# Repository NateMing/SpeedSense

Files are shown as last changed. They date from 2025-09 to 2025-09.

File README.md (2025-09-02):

# Radar Speed Sign - Custom PCBs

Custom PCB designs for SpeedSense, developed using KiCAD.

## Project Overview

This repository contains the custom PCB designs created for SpeedSense. The PCBs include a main control board and a custom 7-segment display module designed specifically for this application.

## Project Structure

```
├── SDP25_MainPCB_V2/          # Latest main PCB design (v2.1)
├── SDP25_MainPCB/             # Original main PCB design
├── Drill Files/               # Manufacturing files
│   ├── Main PCB 2.1/         # Latest drill files
│   ├── Main PCB/             # Original drill files
│   └── 7 seg/                # 7-segment display drill files
└── segment.kicad_pcb          # 7-segment display PCB
```

## Hardware Components

### Main Control PCB (v2.1)
- **File**: `SDP25_MainPCB_V2.kicad_pcb`
- **Purpose**: Main control board for radar speed sign system
- **Features**: 4-layer PCB design with power and ground planes
- **Layers**: Front/Back copper, Power, Ground
- **Design Rules**: 0.2mm minimum clearance, 0.25mm minimum track width

### Custom 7-Segment Display PCB
- **File**: `segment.kicad_pcb`
- **Purpose**: Large format 7-segment display module for vehicle speed display

## Getting Started

### Prerequisites
- KiCAD 7.0 or later

## Manufacturing Files

Ready-to-manufacture Gerber files are available in:
- `SDP25_MainPCB_V2/Gerbers/` - Latest main PCB
- `Drill Files/Main PCB 2.1/` - Corresponding drill files
- `Drill Files/7 seg/` - 7-segment display files

### File Types Included
- **Gerber files** (.gtl, .gbl, .gts, .gbs, etc.)
- **Drill files** (.drl)
- **Pick and place** (.gbr)
- **Job files** (.gbrjob)

## Design Specifications

- **Board thickness**: Standard 1.6mm
- **Minimum track width**: 0.25mm
- **Minimum via size**: 0.5mm diameter
- **Minimum hole size**: 0.3mm
- **Layer count**: 4 layers (Main PCB v2.1)

## Version History

- **v2.1** (Latest) - 4-layer design with improved power distribution
- **v1.0** - Initial 2-layer design

## Project Context

These PCBs are part of a larger radar speed sign system developed as a Senior Design Project (SDP). The complete system includes:
- Radar sensor integration
- Microcontroller-based speed processing
- Custom display driver circuitry
- Power management systems

This repository contains only the custom PCB designs created specifically for this project.

## License

This project is for educational purposes as part of academic coursework.

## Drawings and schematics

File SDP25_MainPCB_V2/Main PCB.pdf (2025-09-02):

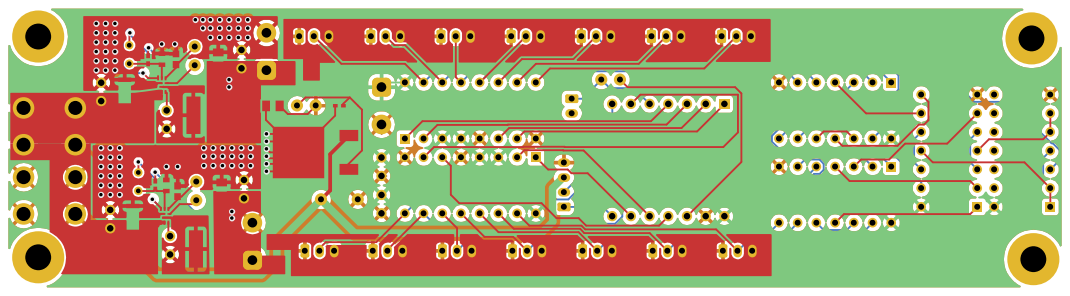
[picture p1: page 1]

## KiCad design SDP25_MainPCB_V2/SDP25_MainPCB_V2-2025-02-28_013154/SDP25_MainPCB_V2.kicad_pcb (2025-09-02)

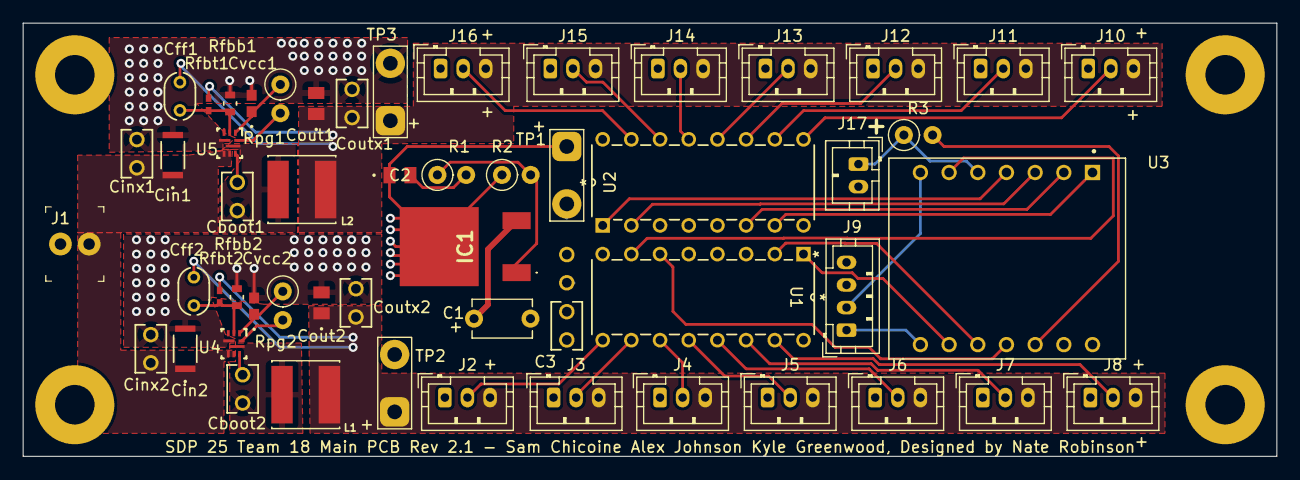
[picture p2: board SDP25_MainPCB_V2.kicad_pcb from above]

Board: 4 copper layers, 111.0 x 38.4 mm, 55 parts (1 on the bottom side), 42 nets.

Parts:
C1: 10uF; C_Disc_D5.1mm_W3.2mm_P5.00mm
C2: 22uF; CAP_GRM21B_MUR
C3, C4: 0.1uF; CAP_FG18_TDK
Cboot1, Cboot2: 0.1uF; CAP_FG18_TDK
Cff1, Cff2: 15pF; CAP_FA18_TDK
Cin1, Cin2: 33uF; CAP_3216_TDK
Cinx1, Cinx2: 0.1uF; CAP_FG18_TDK
Cout1, Cout2: 22uF; CAP_GRM21B_MUR
Coutx1, Coutx2: 0.1uF; CAP_FG18_TDK
Cvcc1, Cvcc2: 1uF; cap_UMK107ABJ474KA-T_TAY
IC1: 5V Voltage Reg.; AZ1084CDADJTRG1
J1: Battery Conn; PinHeader_1x2_P2.54mm_Drill1.02mm
J2: D1PCB1; JST_PH_B3B-PH-K_1x03_P2.00mm_Vertical
J3: D1PCB2; JST_PH_B3B-PH-K_1x03_P2.00mm_Vertical
J4: D1PCB3; JST_PH_B3B-PH-K_1x03_P2.00mm_Vertical
J5: D1PCB4; JST_PH_B3B-PH-K_1x03_P2.00mm_Vertical
J6: D1PCB5; JST_PH_B3B-PH-K_1x03_P2.00mm_Vertical
J7: D1PCB6; JST_PH_B3B-PH-K_1x03_P2.00mm_Vertical
J8: D1PCB7; JST_PH_B3B-PH-K_1x03_P2.00mm_Vertical
J9: Radar Conn; JST_PH_B4B-PH-K_1x04_P2.00mm_Vertical
J10: D2PCB1; JST_PH_B3B-PH-K_1x03_P2.00mm_Vertical
J11: D2PCB2; JST_PH_B3B-PH-K_1x03_P2.00mm_Vertical
J12: D2PCB3; JST_PH_B3B-PH-K_1x03_P2.00mm_Vertical
J13: D2PCB4; JST_PH_B3B-PH-K_1x03_P2.00mm_Vertical
J14: D2PCB5; JST_PH_B3B-PH-K_1x03_P2.00mm_Vertical
J15: D2PCB6; JST_PH_B3B-PH-K_1x03_P2.00mm_Vertical
J16: D2PCB7; JST_PH_B3B-PH-K_1x03_P2.00mm_Vertical
J17: Setup Connector; JST_PH_B2B-PH-K_1x02_P2.00mm_Vertical
L1, L2: 1uH; IND_VLS6045EX-1R0N
R1: 150; R_Axial_DIN0207_L6.3mm_D2.5mm_P2.54mm_Vertical
R2: 56; R_Axial_DIN0207_L6.3mm_D2.5mm_P2.54mm_Vertical
R3: R; R_Axial_DIN0207_L6.3mm_D2.5mm_P2.54mm_Vertical
Rfbb1, Rfbb2: 30k; RES_RC0603_YAG
Rfbt1, Rfbt2: 95.3k; RC0402N_VIS
Rpg1, Rpg2: 100k; R_Axial_DIN0207_L6.3mm_D2.5mm_P2.54mm_Vertical
TP1: TP 5V; TestPoint_2Pads_Pitch5.08mm_Drill1.3mm
TP2, TP3: TP 2.5V; TestPoint_2Pads_Pitch5.08mm_Drill1.3mm
U1: BCD-To-7 2; N16
U2: BCD-TO-7 1; N16
U3: XIAO ESP32C3; MODULE_113991054
U4, U5: TPS566238PRQFR; RQF0009A

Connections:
/SW1: Cboot1.1, L2.1, U5.8 (SW)
/SW2: Cboot2.1, L1.1, U4.8 (SW)
/Vin: C1.1, Cin1.1, Cin2.1, Cinx1.1, Cinx2.1, IC1.3 (INPUT), J1.1, J9.3, U4.5 (VIN), U4.6 (VIN), U5.5 (VIN), U5.6 (VIN)
/Vout1: Cff2.1, Cout2.1, Coutx2.1, J2.3, J3.3, J4.3, J5.3, J6.3, J7.3, J8.3, L1.2, Rfbt2.1, TP2.1
/Vout2: Cff1.1, Cout1.1, Coutx1.1, J10.3, J11.3, J12.3, J13.3, J14.3, J15.3, J16.3, L2.2, Rfbt1.1, TP3.1
/Vout3: C2.1, C3.2, C4.1, IC1.2 (OUTPUT), R2.1, TP1.1, U1.3 (*LT), U1.4 (*BL), U1.16 (VCC), U2.3 (*LT), U2.4 (*BL), U2.16 (VCC), U3.14 (VUSB)
GND: C1.2, C2.2, C3.1, C4.2, Cin1.2, Cin2.2, Cinx1.2, Cinx2.2, Cout1.2, Cout2.2, Coutx1.2, Coutx2.2, Cvcc1.2, Cvcc2.2, J1.2, J2.1, J3.1, J4.1, J5.1, J6.1, J7.1, J8.1, J9.4, J10.1, J11.1, J12.1, J13.1, J14.1, J15.1, J16.1, J17.2, R1.2, Rfbb1.2, Rfbb2.2, TP1.2, TP2.2, TP3.2, U1.5 (*LE), U1.8 (GND), U2.5 (*LE), U2.8 (GND), U3.13 (GND), U4.4 (PGND), U5.4 (PGND)
unnamed: IC1.1 (ADJ), R1.1, R2.2
unnamed: J6.2, U1.13 (A)
unnamed: J5.2, U1.12 (B)
unnamed: J4.2, U1.11 (C)
unnamed: U1.7 (D0), U3.6 (D5)
unnamed: U1.1 (D1), U3.9 (D8)
unnamed: U1.2 (D2), U3.10 (D9)
unnamed: U1.6 (D3), U3.11 (D10)
unnamed: J3.2, U1.10 (D)
unnamed: J2.2, U1.9 (E)
unnamed: J8.2, U1.15 (F)
unnamed: J7.2, U1.14 (G)
unnamed: J14.2, U2.13 (A)
unnamed: J13.2, U2.12 (B)
unnamed: J12.2, U2.11 (C)
unnamed: U2.7 (D0), U3.1 (D0)
unnamed: U2.1 (D1), U3.4 (D3)
unnamed: U2.2 (D2), U3.3 (D2)
unnamed: U2.6 (D3), U3.2 (D1)
unnamed: J11.2, U2.10 (D)
unnamed: J10.2, U2.9 (E)
unnamed: J16.2, U2.15 (F)
unnamed: J15.2, U2.14 (G)
unnamed: J17.1, R3.1, U3.5 (D4)
unnamed: J9.1, U3.8 (RX_D7)
unnamed: J9.2, U3.7 (TX_D6)
unnamed: R3.2, U3.12 (VCC_3V3)
unnamed: Cboot2.2, U4.7 (BST)
unnamed: Cff2.2, Rfbb2.1, Rfbt2.2, U4.2 (FB)
unnamed: Rpg2.2, U4.9 (SS)
unnamed: Cvcc2.1, Rpg2.1, U4.1 (VCC)
unnamed: Cboot1.2, U5.7 (BST)
unnamed: Cff1.2, Rfbb1.1, Rfbt1.2, U5.2 (FB)
unnamed: Rpg1.2, U5.9 (SS)
unnamed: Cvcc1.1, Rpg1.1, U5.1 (VCC)

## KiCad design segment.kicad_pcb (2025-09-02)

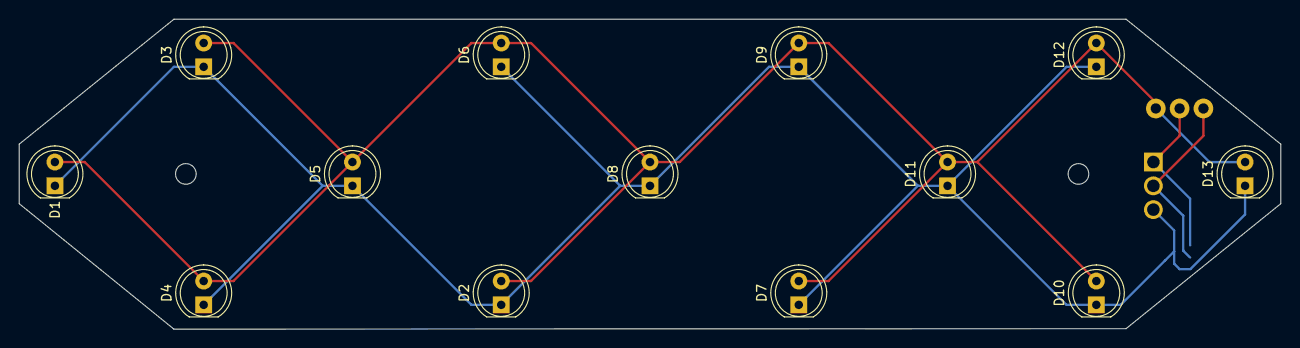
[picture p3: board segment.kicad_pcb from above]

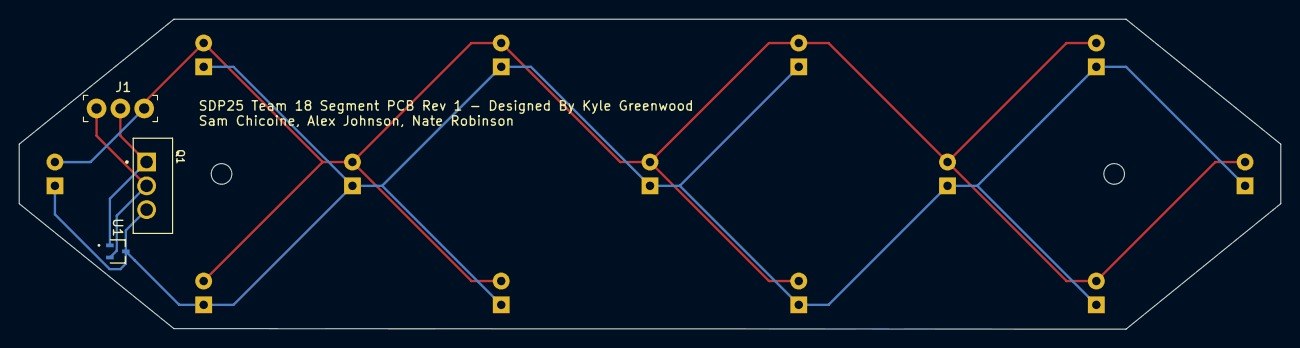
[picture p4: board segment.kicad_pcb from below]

Board: 2 copper layers, 134.6 x 33.1 mm, 16 parts (3 on the bottom side), 4 nets.

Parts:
D1, D2, D3, D4, D5, D6, D7, D8, D9, D10, D11, D12, D13: LED; LED_D5.0mm
J1: 61300311121; PinHeader_1x3_P2.54_Drill1.1mm
Q1: DN2540N5-G; TO254P1066X482X2286-3
U1: DMG1012UW-7; SOT_12UW-7_DIO-L

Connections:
unnamed: D1.2 (A), D2.2 (A), D3.2 (A), D4.2 (A), D5.2 (A), D6.2 (A), D7.2 (A), D8.2 (A), D9.2 (A), D10.2 (A), D11.2 (A), D12.2 (A), D13.2 (A), J1.3
unnamed: D1.1 (K), D2.1 (K), D3.1 (K), D4.1 (K), D5.1 (K), D6.1 (K), D7.1 (K), D8.1 (K), D9.1 (K), D10.1 (K), D11.1 (K), D12.1 (K), D13.1 (K), Q1.3, U1.3 (S)
unnamed: J1.1, Q1.2, U1.2 (D)
unnamed: J1.2, Q1.1, U1.1 (G)
